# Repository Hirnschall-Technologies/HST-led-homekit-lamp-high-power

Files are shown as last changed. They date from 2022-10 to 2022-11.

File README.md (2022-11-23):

# High Power LED Lamp (HomeKit enabled, dimmable)
I designed this LED lighting system as a replacement for old halogen R7S uplights.      
These lamps often use high power (400W) bulbs outputing (according to the manufacturer) around 8800 lumen. Meanwhile the only off the shelf LED uplights I could find output 2000 lumen while using around 25W. Furthermore, altough replacement cob LEDs for R7S sockets are available they are typically "20W". I tested several of them and they started at around 15W, after around one hour they only used 10W, they are not bright enough, and they started flickering from time to time.

Also, I dislike how modern LED uplights have to be replaced entirely if a fault with the LEDs or dirver circuit occurs.
Using a modular design, we can reduce waste and wast less power.

### Features
- [x] High power Cree XHP50.3 LEDs (efficient, high CRI 90+) 
- [x] Modular design (2, 4, or 6 LEDs) 
- [x] Dimmable
- [x] Up to 108W, approx 12000 lumen
- [x] Homekit enabled (uses esp8266)
- [x] Manual On/Off switch in addition to Homekit (I use a 433MHz remote)
- [x] Uses 12V to 48V
- [x] Temperature sensor on each LED daughter board
- [x] Each LED on a separate daughter board, thus each led can be raplaced easily
- [x] Open source (Arduino compatible)

### References
The most useful resource for this project was SDG Electronics long-lasting video series on designing an LED ring-light for his microscope using the slightly older Cree XHP50.2 LEDs, as well as his modular LED driver board series.

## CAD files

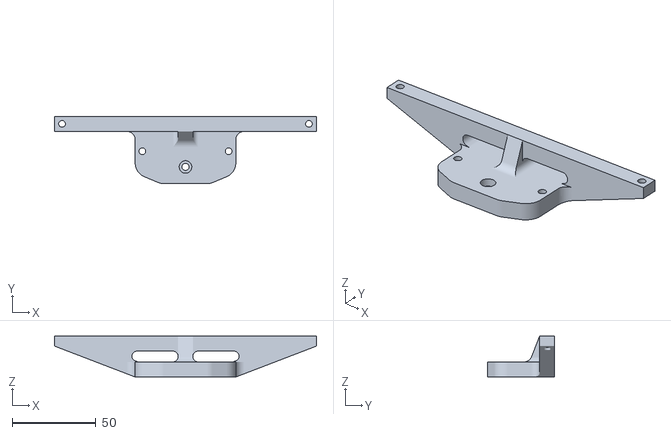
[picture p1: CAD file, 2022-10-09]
stl/led-controller-bracket.stl
156.2 x 40.2 x 24.4

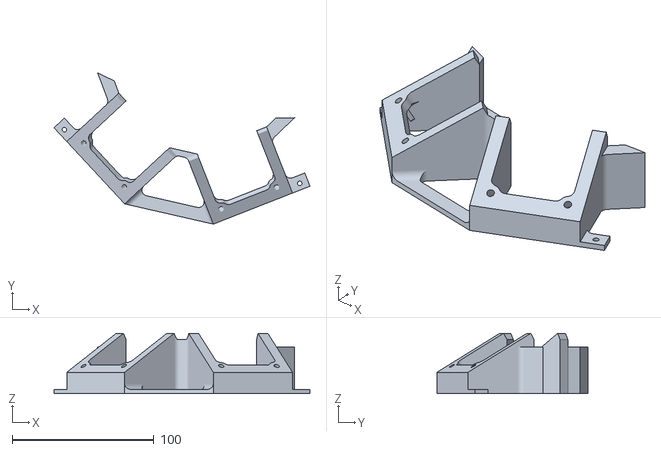
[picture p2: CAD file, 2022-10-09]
stl/led-mount-asymmetrical-2.stl
180.6 x 106.7 x 42.6

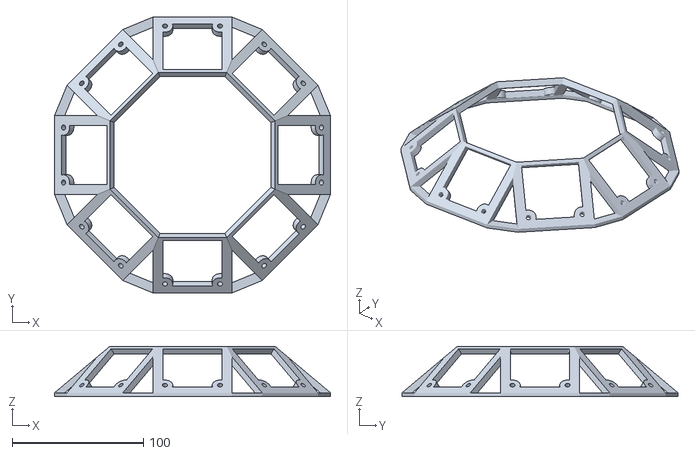
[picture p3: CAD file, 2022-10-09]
stl/led-mount-symmetrical.stl
210.0 x 210.0 x 38.4

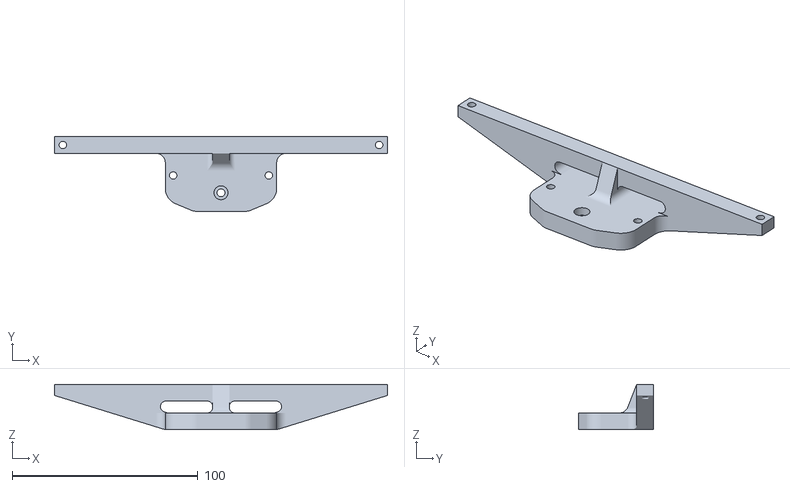
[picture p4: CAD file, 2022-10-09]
stl/led-controller-bracket-2.stl
179.3 x 40.3 x 24.4

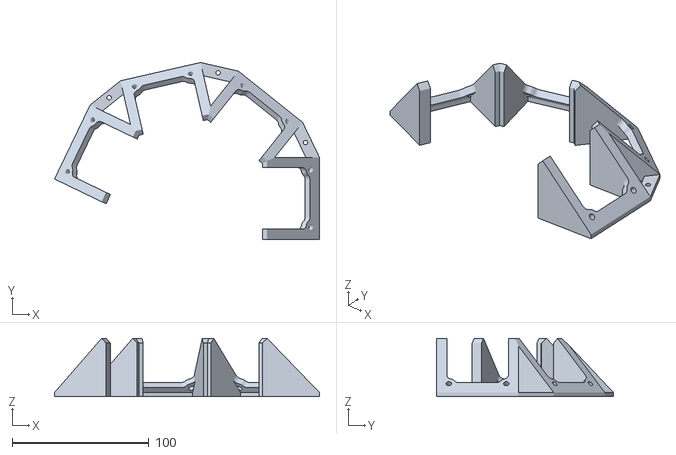
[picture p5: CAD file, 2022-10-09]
stl/led-mount-asymmetrical-4.stl
193.6 x 129.3 x 42.6

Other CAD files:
led-controller-bracket.CATPart
led-mount-asymmetrical.CATPart
led-mount-symmetrical.CATPart
stl/led-controller-bracket-2.CATPart
stl/led-mount-asymmetrical-4.CATPart

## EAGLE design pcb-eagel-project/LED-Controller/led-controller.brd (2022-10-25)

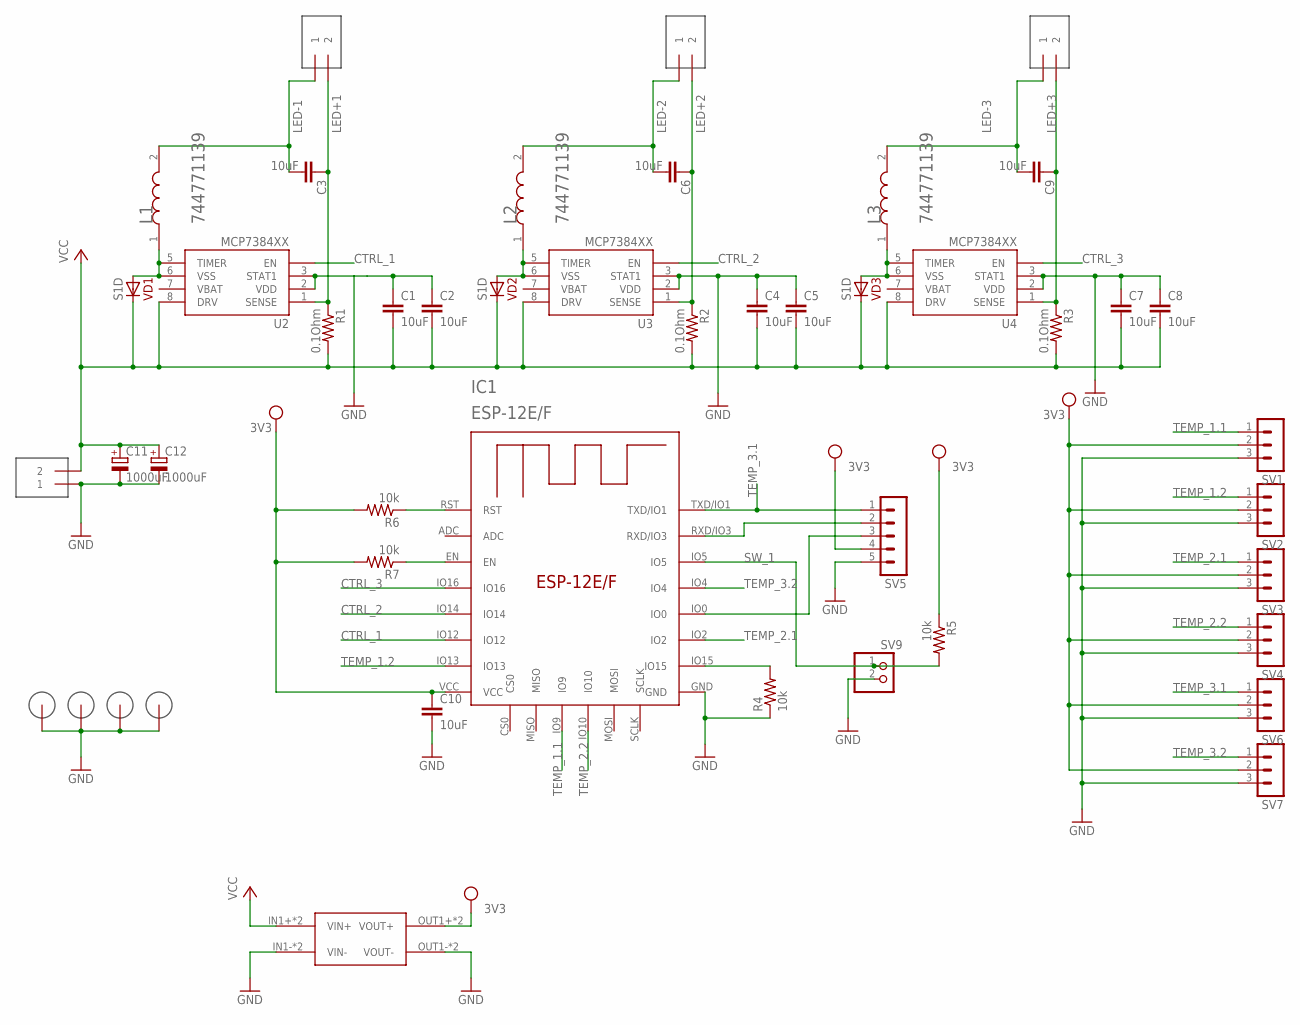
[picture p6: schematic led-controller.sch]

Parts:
C1, C2, C3, C4, C5, C6, C7, C8, C9, C10: 10uF; C0805K
C11, C12: 1000uF; E5-13
H1, H2, H3, H4: 3MM_HOLE
IC1: ESP-12E/F; ESP-12E
L1, L2, L3: 39uH; WURTH_ELECTRONICS_744771139_0
R1, R2, R3: 0.1Ohm; R1206
R4, R5, R6, R7: 10k; R0805
SV1, SV2, SV3, SV4, SV6, SV7: MA03-1
SV5: MA05-1
SV9: PINHD-1X2; 1X02
U2, U3, U4: MCP7384XX; MSOP8
U$3, U$5, U$7, U$8: TERMINAL_2P; KF301-2P
U$10: MP1584; DC-BRICK
VD1, VD2, VD3: S1D; DO214AC

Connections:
3V3: C10.1, IC1.VCC, R5.1, R6.2, R7.2, SV1.2, SV2.2, SV3.2, SV4.2, SV5.4, SV6.2, SV7.2, U$10.OUT1+ (VOUT+), U$10.OUT2+ (VOUT+)
CTRL_1: IC1.IO12, U2.4 (EN)
CTRL_2: IC1.IO14, U3.4 (EN)
CTRL_3: IC1.IO16, U4.4 (EN)
GND: C1.1, C2.1, C4.1, C5.1, C7.1, C8.1, C10.2, C11.-, C12.-, H1.P$1, H1.P$2, H1.P$3, H1.P$4, H1.P$5, H1.P$6, H1.P$7, H1.P$8, H1.P$9, H2.P$1, H2.P$2, H2.P$3, H2.P$4, H2.P$5, H2.P$6, H2.P$7, H2.P$8, H2.P$9, H3.P$1, H3.P$2, H3.P$3, H3.P$4, H3.P$5, H3.P$6, H3.P$7, H3.P$8, H3.P$9, H4.P$1, H4.P$2, H4.P$3, H4.P$4, H4.P$5, H4.P$6, H4.P$7, H4.P$8, H4.P$9, IC1.GND, R4.1, SV1.3, SV2.3, SV3.3, SV4.3, SV5.5, SV6.3, SV7.3, SV9.2, U2.2 (VDD), U2.3 (STAT1), U3.2 (VDD), U3.3 (STAT1), U4.2 (VDD), U4.3 (STAT1), U$8.1, U$10.IN1- (VIN-), U$10.IN2- (VIN-), U$10.OUT1- (VOUT-), U$10.OUT2- (VOUT-)
LED+1: C3.1, R1.1, U2.1 (SENSE), U$3.2
LED+2: C6.1, R2.1, U3.1 (SENSE), U$5.2
LED+3: C9.1, R3.1, U4.1 (SENSE), U$7.2
LED-1: C3.2, L1.2, U$3.1
LED-2: C6.2, L2.2, U$5.1
LED-3: C9.2, L3.2, U$7.1
unnamed: IC1.RST, R6.1
unnamed: IC1.EN, R7.1
unnamed: L2.1, U3.5 (TIMER), U3.6 (VSS), VD2.A
unnamed: L3.1, U4.5 (TIMER), U4.6 (VSS), VD3.A
unnamed: L1.1, U2.5 (TIMER), U2.6 (VSS), VD1.A
unnamed: IC1.IO15, R4.2
unnamed: IC1.IO0, SV5.3
unnamed: IC1.RXD/IO3, SV5.2
SW_1: IC1.IO5, R5.2, SV9.1
TEMP_1.1: IC1.IO9, SV1.1
TEMP_1.2: IC1.IO13, SV2.1
TEMP_2.1: IC1.IO2, SV3.1
TEMP_2.2: IC1.IO10, SV4.1
TEMP_3.1: IC1.TXD/IO1, SV5.1, SV6.1
TEMP_3.2: IC1.IO4, SV7.1
VCC: C1.2, C2.2, C4.2, C5.2, C7.2, C8.2, C11.+, C12.+, R1.2, R2.2, R3.2, U2.8 (DRV), U3.8 (DRV), U4.8 (DRV), U$8.2, U$10.IN1+ (VIN+), U$10.IN2+ (VIN+), VD1.C, VD2.C, VD3.C

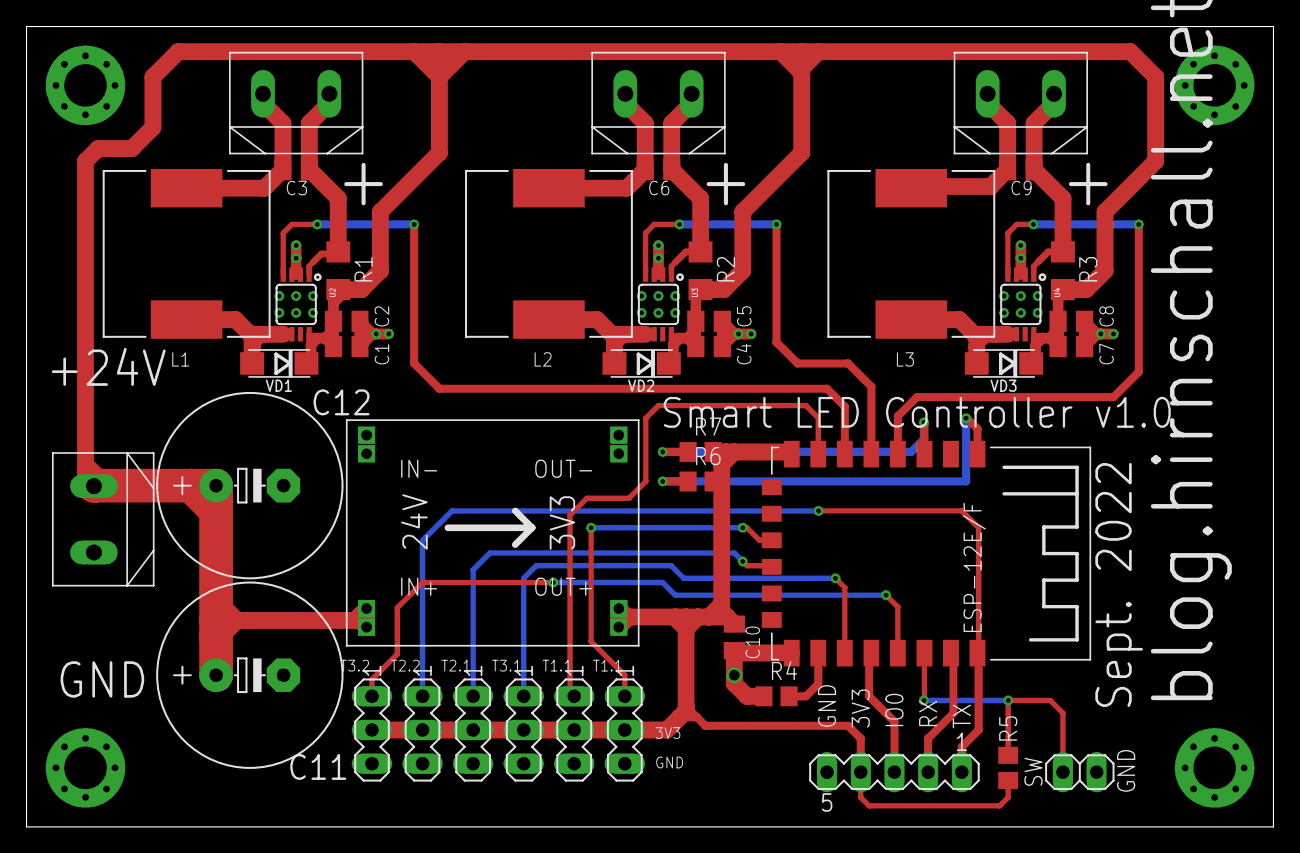
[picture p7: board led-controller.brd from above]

Board: 2 copper layers, 94.0 x 60.3 mm, 46 parts (0 on the bottom side), 27 nets.

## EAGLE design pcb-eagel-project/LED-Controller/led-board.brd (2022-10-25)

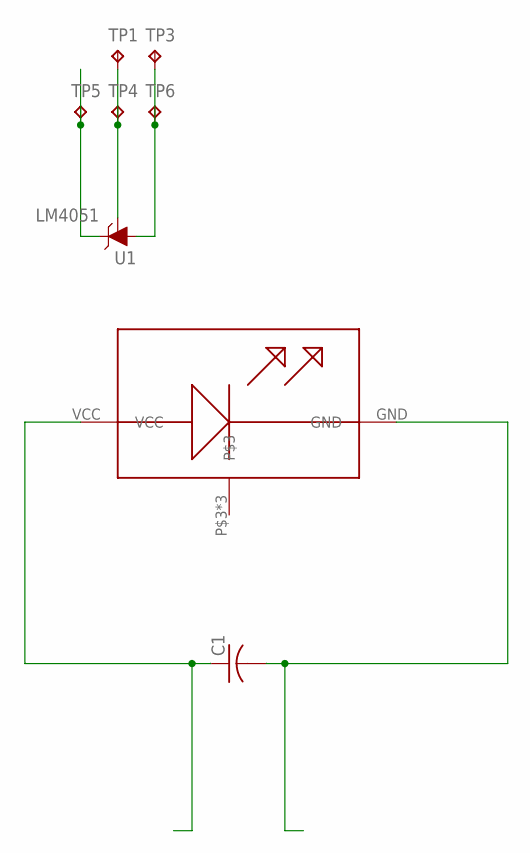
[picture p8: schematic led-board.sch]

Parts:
C1: C-USC0805; C0805
TP1, TP3, TP4, TP5, TP6: TPTP20SQ; TP20SQ
U1: LM4051; SOT23-3
U$3: XHP50.3

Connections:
unnamed: C1.1, U$3.VCC
unnamed: C1.2, U$3.GND
unnamed: TP1.TP, TP4.TP, U1.1 (ADJ)
unnamed: TP5.TP, U1.2 (C)
unnamed: TP3.TP, TP6.TP, U1.3 (A)

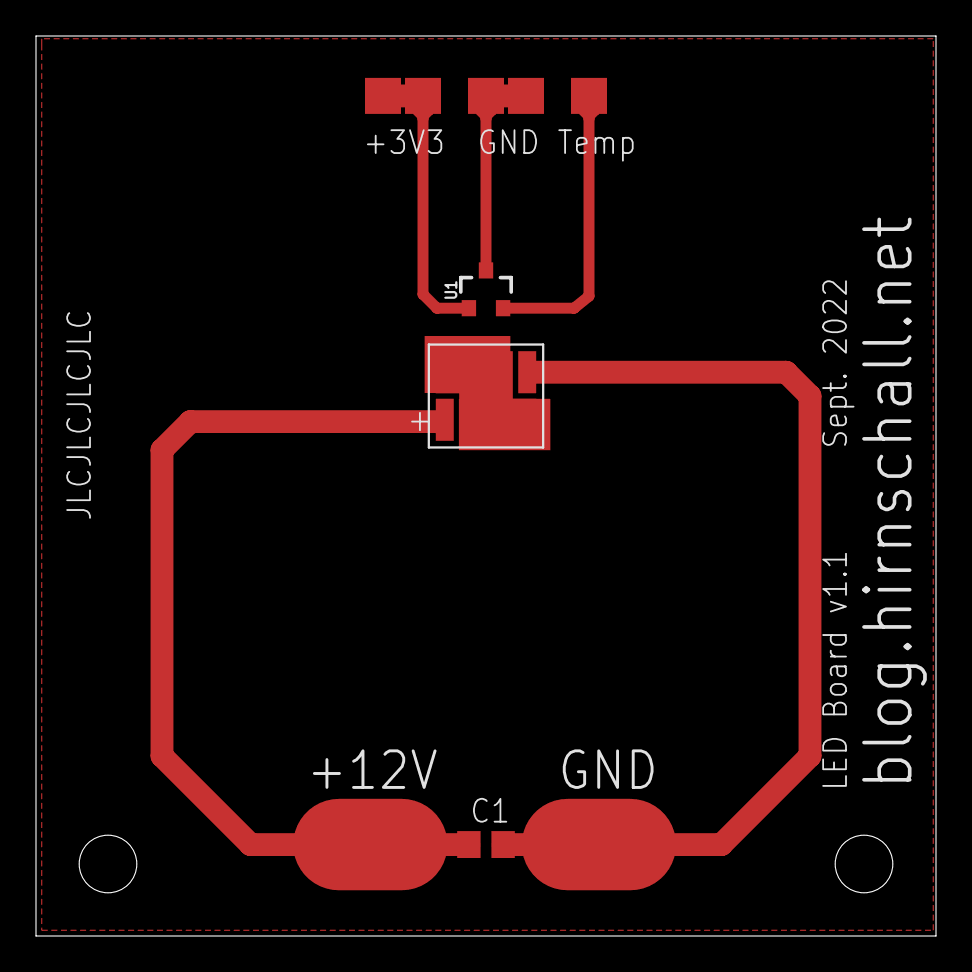
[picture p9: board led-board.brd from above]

Board: 2 copper layers, 50.0 x 50.0 mm, 8 parts (0 on the bottom side), 5 nets.

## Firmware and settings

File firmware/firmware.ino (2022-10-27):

//---------------------------------------------------
#include <ESP8266WiFi.h>
const char *ssid = "";
const char *password = "";
//---------------------------------------------------
#include <ESP8266WebServer.h>
ESP8266WebServer server(80);  //listen to port 80
//---------------------------------------------------
#define LED_1 12
#define LED_2 14
#define LED_3 16

#define FAN_PIN 10    //T2.1
#define REMOTE_PIN 5    //SW

#define MAX_SAFE_TEMP_WO_FAN 75 
#define COOLDOWN_TEMP_WO_FAN 65 
#define MAX_SAFE_TEMP 80    //cannot measure higher using 0-2V
#define COOLDOWN_TEMP 70    //if MAX_SAFE_TEMP is hit, reduce max power to MAX_SAFE_PWM until temperature reaches COOLDOWN_TEMP
#define MAX_SAFE_PWM 153    // 60%

#define TEMP_READ_INTERVALL_IN_MS 10000

int remotePinHigh = 0;
int fanStatus = 0;
int overheated = 0;
int currentStatus = 0;
int statusChanged = 0;
int currentBrightness = 100;

unsigned long previousMillis =0;

float getTemperatureInDegC(){
  //see datasheet for TMP236 for details on conversion
    return -(5/98.0)*400+analogRead(A0)*(2/1024.0)*1000*(5/98.0);
}


void setPosition() {
  Serial.println("New request for \"/\"");
  if(server.hasArg("setenabled")){
    statusChanged = 1;
    currentStatus = (server.arg("setenabled").toInt() > 0);
    server.send ( 200, "text/html",  String(currentStatus)  );
  }
  else if(server.hasArg("getstatus"))
    server.send ( 200, "text/html",  String(currentStatus)  );
  else if(server.hasArg("setbrightness")){
    statusChanged = 1;
    if(server.arg("setbrightness").toInt() >=0 && server.arg("setbrightness").toInt() <=100)
      currentBrightness = server.arg("setbrightness").toInt();
    server.send ( 200, "text/html",  String(currentBrightness)  );
  }
  else if(server.hasArg("getbrightness"))
    server.send ( 200, "text/html",  String(currentBrightness)  );
  else if(server.hasArg("temperature"))
    server.send ( 200, "application/json",  "{\"temperature\": " + String(getTemperatureInDegC()) + "}" );
  else
    server.send ( 200, "text/html",  String(currentStatus)  );
}

void setup() {
  analogWriteFreq(100);    //less than 500 Hz for linear dimming with AL8860Q
  
  pinMode(LED_1,OUTPUT);
  pinMode(LED_2,OUTPUT);
  pinMode(LED_3,OUTPUT);
  analogWrite(LED_1,0);
  analogWrite(LED_2,0);
  analogWrite(LED_3,0);

  
  pinMode(FAN_PIN,OUTPUT);
  digitalWrite(FAN_PIN,LOW);
  
  Serial.begin(115200); //start the serial output
  Serial.println();
  Serial.println("Starting up");
  
  
  Serial.print("Connecting to ");
  Serial.println(ssid);
  // Print local IP address and start web server
  Serial.println("");
  //set mac address
  uint8_t mac[6] {0x5C, 0x26, 0x19, 0x40, 0x86, 0x62}; 
  wifi_set_macaddr(0, const_cast<uint8*>(mac));
  //disable ap advertising 
  WiFi.mode(WIFI_STA);
  //connect to wifi
  WiFi.begin(ssid, password);
  while (WiFi.status() != WL_CONNECTED) {
    Serial.print(".");
    delay(500);
  }
  Serial.println("WiFi connected.");
  Serial.println("IP address: ");
  Serial.println(WiFi.localIP());

  
  Serial.println("------------------------------");
  server.on ( "/", setPosition );
  server.begin(); //start the webserver
  Serial.println("Webserver started");

  Serial.println("Startup finished");
  Serial.println("****************");
  pinMode(LED_BUILTIN, OUTPUT);
  digitalWrite(LED_BUILTIN, HIGH);
}

void loop() {
  server.handleClient();  //process all the requests for the Webserver
  unsigned long currentMillis = millis();
  if (previousMillis > currentMillis || currentMillis - previousMillis >= TEMP_READ_INTERVALL_IN_MS)
  {
    previousMillis = currentMillis;
    float temp = getTemperatureInDegC();
    Serial.print("Temp at ");
    Serial.print(currentMillis);
    Serial.print("ms: ");
    Serial.println(temp);

    //control fan based on temp 
    if (temp > MAX_SAFE_TEMP_WO_FAN && currentStatus && !fanStatus){
      fanStatus = 1;
      digitalWrite(FAN_PIN, HIGH);
    }

    if(temp < COOLDOWN_TEMP_WO_FAN && currentStatus && fanStatus){
      fanStatus= 0;
      digitalWrite(FAN_PIN, LOW);
    }
    if( temp > MAX_SAFE_TEMP && currentStatus){
      overheated = 1;
      statusChanged = 1;
      Serial.println("overheating! - limiting to 60% power");
    }
    if( temp < COOLDOWN_TEMP && overheated){
      overheated = 0;
      statusChanged = 1;
      Serial.println("overheating avoided - allowing 100% power");
    }
  }
  if(statusChanged){
    statusChanged = 0;
    if(currentStatus){
      int safePWM;
      if(overheated)
        safePWM = (currentBrightness/100.0*255)<MAX_SAFE_PWM?(currentBrightness/100.0*255):MAX_SAFE_PWM;
      else
        safePWM = currentBrightness/100.0*255;
      analogWrite(LED_1,safePWM);
      delay(25);
      analogWrite(LED_2,safePWM);
      delay(25);
      analogWrite(LED_3,safePWM);
    }else{
      analogWrite(LED_3,0);
      delay(25);
      analogWrite(LED_2,0);
      delay(25);
      analogWrite(LED_1,0);
    }
  }

  if(!remotePinHigh && digitalRead(REMOTE_PIN) == HIGH){
    Serial.println("remote input - toggle on/off");
    remotePinHigh = 1;
    statusChanged = 1;
    currentStatus = !currentStatus;
  }
  if(remotePinHigh && digitalRead(REMOTE_PIN) == LOW){
    Serial.println("reset remote input");
    remotePinHigh = 0;
    }
}

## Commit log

2022-10-09 first draft of an asymmetrical 6 led layout/mount for uplights
    [led-controller-bracket-2.CATPart, led-controller-bracket-2.stl, led-controller-bracket.CATPart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]
2022-10-10 add ed pcb source files - autodesk eagel project
    [led-board.brd, led-board.sch, led-controller.brd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]

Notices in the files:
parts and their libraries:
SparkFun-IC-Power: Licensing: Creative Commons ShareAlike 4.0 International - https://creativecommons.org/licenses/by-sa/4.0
